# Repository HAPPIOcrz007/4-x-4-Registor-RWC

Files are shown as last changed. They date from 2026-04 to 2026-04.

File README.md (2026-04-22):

# 4×4 Register PCB — Read / Write / Asynchronous Clear

A first-year B.Tech Digital Electronics project implementing a **4×4 register file** using standard 74-series TTL ICs, progressing from Logisim simulation through breadboard prototyping to a fabricated KiCad PCB — verified live at the **Circuit Conclave Hackathon 2026, MIT World Peace University**.

> 🏅 **Recommended by the Department Head and leading faculty of the Department of Electrical & Electronics Engineering, MIT-WPU, as a future laboratory teaching kit** — recognised for its compact 15×15 cm form factor, intuitive layout, and pedagogical value for FY B.Tech students.

PCB top view — 4 Row Memory Storage

---

## ✨ Features

- **4 registers × 4 bits each** — 16 bits total volatile storage
- **2-bit address bus** for row selection via SN74LS139AN decoder
- **Synchronous write** — data latched on rising edge of NE555P astable clock (0.5 Hz)
- **Tri-state buffered read** — selected register drives shared LED output bus via SN74LS244N
- **Asynchronous clear** — active-low reset of addressed register, independent of clock
- **Single RW push-button** for mode control (default = read, pressed = write)
- **4 output LEDs** (CQY99) displaying bus values in real time
- **Compact 15×15 cm PCB** — all 31 components placed and routed on a 2-layer board
- **Single +5V supply** (see Hardware Notes for 6V field experience)

---

## 🏆 Presented At

**Circuit Conclave Hackathon 2026**
DoEEE & prismlabs Student Club | MIT World Peace University, Pune
FY B.Tech E&CE — Division 23 | Academic Year 2025–26

The PCB was demonstrated live before a jury comprising faculty from Basic Electrical Engineering, Digital Electronics, and an external industry examiner. The board powered up cleanly and passed all functional tests on the day — write, read, hold, and clear verified across all four register addresses.

**The project received special recognition from the Department Head and senior faculty of the DoEEE, who recommended it be adopted as a hands-on laboratory teaching kit for future first-year batches.**

### Team
| Member | Role |
|---|-----|
| Harshvardhan M Rathod | Pcb Design, Logical iterations, connections, development, verifications and ordering |
| Alok Deep Verma | report and ppt writing and printing |

**Faculty Mentor:** Dr. Sarika Patil &nbsp;|&nbsp; **Digital Electronics:** Dr. Manisha Ingle

---

## 📂 Repository Structure

```
.
├── 4X4_MEMORY_READ_WRITE.circ           # Logisim Evolution simulation file
├── BOM.pdf                              # Bill of Materials (KiCad export)
├── Component box/                       # Custom component libraries
│   ├── <IC or switch folders>/          #   KiCad symbols, footprints, STEP models
│   └── License.txt
├── KiKad/                               # KiCad project files
│   ├── 4-x-4-Registor-RWC.kicad_pcb    #   PCB layout
│   ├── 4-x-4-Registor-RWC.kicad_sch    #   Schematic
│   ├── 4-x-4-Registor-RWC.kicad_pro    #   Project file
│   ├── 4-x-4-Registor-RWC.kicad_prl    #   Project local settings
│   └── 4-x-4-Registor-RWC.pretty/      #   Custom footprints
├── RAM-project-001.csv                  # Raw BOM CSV export
├── Report.pdf                           # Full project report
├── sm_black_top.png                     # PCB render — top view (KiCad)
├── output.pdf                           # schematic drawing sheet pdf
├── pcb_output.pdf                       # pcb order copy pdf
└── README.md                            # This file
```

---

## 📦 Bill of Materials

**Total: 31 components | 2-layer PCB | Single +5V supply**

| Category | Qty | Key Parts |
|---|-----|---|
| ICs | 11 | SN74LS175N ×4, SN74LS139AN, SN74LS244N ×2, SN74LS08N, SN7402N, SN7432N, NE555P |
| Switches | 8 | SPST inputs (D0–D3, A0–A1), RW push-button, Clear push-button |
| LEDs | 4 | CQY99 — output bus indicators (Bits 0–3) |
| Resistors | 6 | 220 Ω ×4 (LED limiting), 10 kΩ + 68 kΩ (NE555P timing network) |
| Capacitors | 2 | 0.1 µF ceramic disc — VCC decoupling |
| **Total** | **31** | — |

---

## ⚙️ Operating Modes

| Mode | RW (SWW1) | Address | Clock | CLR\ | Result |
|---|---|---|---|---|---|
| Write | 1 — pressed | Row n | ↑ rising edge | 1 | Data latched into Row n |
| Read | 0 — default | Row n | — | 1 | Row n displayed on OL0–OL3 |
| Hold | 0 | Any | — | 1 | No change |
| Clear | X | Row n | — | 0 — pressed | Selected row reset to 0000 |

**Clock frequency:** `f = 1.44 / [(R1 + 2×R2) × C] = 1.44 / [146 kΩ × 20 µF] ≈ 0.5 Hz`

---

## 🔧 Hardware Notes & Lessons Learned

### Power Supply — 6V Field Operation
The board was designed for a regulated **+5V** supply. During the live demonstration it was powered from a **6V battery**, with a **toggle switch inserted between the battery and the VCC patch point** for clean power-on/off control. The 74LS-series ICs functioned correctly at 6V for the duration of the demo. Note that 6V is outside the 74LS absolute maximum rating (5V ±5%), so a regulated 5V supply (e.g. 7805 linear regulator or USB power module) is recommended for sustained operation.

### Noise on SN74LS175N — Decoupling Lesson
During live testing, switching noise was observed being picked up on the **SN74LS175N (Quad D Flip-Flop) VCC pins**, occasionally causing spurious state changes on the output. The examining faculty identified the root cause immediately:

**Fix recommended by faculty:**
> Add a **0.1 µF ceramic capacitor between VCC and GND at every IC's power pins**, placed as physically close to each DIP package as possible.

The existing BOM includes two 0.1 µF decoupling caps (CC1, CC2). The lesson: **every IC in a TTL design should have its own dedicated decoupling capacitor** — not just selected ICs. Switching transients from multiple ICs sharing the same power rail accumulate and cause exactly this noise behaviour.

**Updated decoupling plan for next PCB revision:**

| IC | KiCad Ref | Decoupling Cap |
|----|---|---|
| SN74LS175N ×4 | D074175–D374175 | 0.1 µF per IC — **×4 to add** |
| SN74LS139AN | D74139 | 0.1 µF — **to add** |
| SN74LS08N | A7408 | 0.1 µF — **to add** |
| SN7402N | N7402 | 0.1 µF — **to add** |
| SN7432N | O7432 | 0.1 µF — **to add** |
| NE555P | CNE555 | 0.1 µF — **to add** |
| SN74LS244N ×2 | B074244, B174244 | 0.1 µF — already placed ✓ |

**Total additional caps for Rev 2: +7 × 0.1 µF ceramic disc**

---

## 🖥️ Simulation

The full register file was first verified in **Logisim Evolution** (`4X4_MEMORY_READ_WRITE.circ`) before any hardware was built. All four operating modes — write, read, hold, and clear — were confirmed across all four register addresses in simulation before committing to PCB layout.

---

## 📚 References

- Texas Instruments datasheets: [SN74LS175](https://www.ti.com/lit/gpn/sn74ls175) · [SN74LS139A](https://www.ti.com/lit/gpn/sn74ls139a) · [SN74LS244](https://www.ti.com/lit/gpn/sn74ls244) · [NE555](https://www.ti.com/lit/gpn/ne555)
- M. M. Mano & M. D. Ciletti, *Digital Design*, 5th ed., Pearson
- D. A. Patterson & J. L. Hennessy, *Computer Organisation and Design*, 5th ed., Morgan Kaufmann

---

## 🚀 Future Work

- Add 0.1 µF decoupling capacitor at each IC VCC pin (see Hardware Notes above)
- On-board 7805 / LDO regulator footprint for regulated 5V from a 9V battery
- Expansion connector for 16-LED monitor matrix (as in Logisim simulation)
- FPGA / HDL implementation for direct speed and area comparison
- Formal adoption as DoEEE laboratory teaching kit for future FY B.Tech batches

---

## 📜 License

- **Hardware design files:** CERN OHL v2 (Strongly Reciprocal)
- **Code & documentation:** MIT License

See `LICENSE` for full terms.

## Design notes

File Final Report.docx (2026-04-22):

DR. VISHWANATH KARAD MIT WORLD PEACE UNIVERSITY

School of Engineering & Technology

Department of Electrical & Electronics Engineering

Academic Year: 2025–26

CIRCUIT CONCLAVE HACKATHON 2026

Electronics & Communication Engineering (AI ML), Semester II (Batch 2025-29)

Div: 23 | ORGANIZED BY: DoEEE IN ASSOCIATION with prismlabs Student Club

1. PROJECT OVERVIEW

Project Title: | Design and Implementation of a 4×4 Register File with Synchronous Read/Write and Asynchronous Clear
Division: | —
Team ID: | ________________

2. TEAM REPRESENTATION

All details as per University Records.

Member Role | Full Student Name | Permanent Registration No. (PRN)
Member 1 (Lead) | Harshvardhan Rathod | —————
Member 2 | Alok Deep Verma | —————
Member 3

3. ACADEMIC ENDORSEMENT

Faculty Digital Electronics: Dr. Manisha Ingle & Dr. Sarika Patil

Faculty Basics of Electronics Engineering: _________________________________________________

4. SUBMISSION CHECKLIST (FOR PRISM LABS CORE)

[ ] Official Undertaking Signed by All Members

[ ] Hard Copy of Technical Report Included

[ ] Digital Soft Copy Submitted via Official Link

[ ] Hardware Project Ready for Demonstration

5. OFFICIAL STAMP AREA

Submission Date & Department Stamp: _______________________

OFFICIAL CERTIFICATE OF PARTICIPATION

CIRCUIT CONCLAVE HACKATHON 2026

A Project-Based Learning Initiative | prismlabs & DoEEE

This is to certify that

STUDENT NAME: Harshvardhan Rathod

PRN: ————— | Division: —

has successfully participated in the Circuit Conclave Hackathon 2026, conducted at MIT World Peace University, Pune.

The participant has fulfilled the requirements of the Round 1 Assessment by submitting a functional hardware project and a comprehensive technical report under the guidance of their Faculty Mentor. This certification recognizes their commitment to practical engineering and collaborative problem-solving within the ECE framework.

Date of Issuance: 15th April 2026

OFFICIAL SIGNATORIES

__________________________ Faculty Mentor, DoEEE | __________________________ prismlabs, Student Club | __________________________ FY Coordinator, DoEEE | __________________________ Parul Jadhav, PD, DoEEE

INDEX — CIRCUIT CONCLAVE 2026

Sr. No. | Section Title | Page No.
01 | Abstract | 05
02 | Introduction | 05
03 | Components & Technical Specifications | 05
04 | Circuit Diagram & Working Principle | 05
05 | Hardware Implementation & Assembly | 06
06 | Conclusion & Future Scope | 06
07 | Annexure I: Formal Undertaking by Participants | 07
08 | Section I: Team Acknowledgement & Signatures | 08
09 | Section II: Selection & Official Endorsement | 08
10 | Section III: Round 2 Performance Scorecard | 10

1. ABSTRACT

Executive Summary

This project presents the design, PCB implementation, and functional verification of a 4×4 register file implemented from standard 74-series TTL integrated circuits. The system provides four 4-bit addressable storage registers supporting synchronous clock-triggered write, tri-state bus-buffered read, and asynchronous active-low clear. A NE555P astable circuit generates a 0.5 Hz clock for step-by-step observation. The KiCad PCB design (RAM-project-001) places 31 components using E-Switch SW_100SP1T1B4M2QE for data, address, and control inputs, and CQY99 LEDs for output display. The system was verified through complete functional testing across all register addresses and operating modes, with every test case confirmed correct.

Problem Statement

Engineering education in digital electronics often remains confined to theoretical instruction — students study register files, memory hierarchies, and processor architecture from textbooks without constructing these systems at the hardware level. Within the PBL framework, this project addresses that gap: by designing and building a 4×4 register file from discrete 74-series logic and progressing to a KiCad PCB, the team applied combinational and sequential logic theory, interpreted IC datasheets, managed bus contention, designed clock-gating circuits, and verified operation systematically.

Key Keywords

Register File Architecture | Synchronous Write / Asynchronous Clear | Tri-State Bus Multiplexing | NE555P Astable Clock | TTL Address Decoding

2. INTRODUCTION

Technical Objective

To design and implement a 4×4 addressable register file using 74-series TTL ICs, capable of synchronous clock-triggered write to any of four 4-bit registers selected by a 2-bit address, combinational tri-state read onto a shared LED bus, and asynchronous selective clear — all controlled by individual E-Switch inputs and a NE555P 0.5 Hz clock, implemented as a KiCad PCB.

PBL Alignment

This project directly operationalises five theoretical concepts from the FY B.Tech Digital Electronics curriculum:

- Boolean logic gates (NOR, AND, OR) are physically wired and tested — students observe how the NOR–AND chain generates a qualified clock.
- D flip-flop edge-triggering, hold state, and asynchronous reset are experienced through the 74LS175.
- Address decoding theory is realised in the 74LS139 decoder traced with a logic probe.
- The tri-state bus concept becomes intuitive when the 74LS244 output-enable is toggled and LEDs respond.
- The iterative design cycle — from 30 ICs to 9, then to a KiCad PCB — provides experience of specification, prototype, test, and refinement.

Background Research

The register file is the topmost tier of the memory hierarchy, forming the primary working storage for the ALU in every stored-program processor. Patterson and Hennessy (Computer Organisation and Design, 5th ed.) describe the register file as the fundamental abstraction separating the processor from main memory. Mano and Ciletti (Digital Design, 5th ed.) provide the theoretical basis for D flip-flop register arrays and decoder-based address selection. The 74-series TTL family from Texas Instruments has been the standard educational platform for discrete digital design since the 1970s.

3. COMPONENTS & TECHNICAL SPECIFICATIONS

Bill of Materials (BOM) — KiCad RAM-project-001.csv export. All ICs are standard 74-series TTL in DIP packages from Texas Instruments.

KiCad Ref | Part / Value | Specification | Qty | Purpose | Cost
A7408 | SN74LS08N | Quad AND Gate, DIP-14 | 1 | Write-enable clock gating
B074244, B174244 | SN74LS244N | Octal 3-State Buffer, DIP-20 | 2 | Tri-state read bus
CC1, CC2 | Capacitor | Ceramic Disc, 0.1 µF 50V | 2 | VCC decoupling
CNE555 | NE555P | 555 Timer, DIP-8 | 1 | 0.5 Hz astable clock
CR1 | Resistor | 10 kΩ ¼W axial | 1 | 555 R1 — charge path
CR2 | Resistor | 68 kΩ ¼W axial | 1 | 555 R2 — timing
D74139 | SN74LS139AN | Dual 2-to-4 Decoder, DIP-16 | 1 | Address decoding
D074175–D374175 | SN74LS175N | Quad D Flip-Flop, DIP-16 | 4 | 4-bit register (per row)
DIS0–DIS3 | SW_100SP1T1B4M2QE | E-Switch SPST | 4 | Data input D0–D3
AS0, AS1 | SW_100SP1T1B4M2QE | E-Switch SPST | 2 | Address input A0–A1
N7402 | SN7402N | Quad NOR Gate, DIP-14 | 1 | Row-select clock gating
O7432 | SN7432N | Quad OR Gate, DIP-14 | 1 | Asynchronous clear logic
OL0–OL3 | CQY99 | LED 5mm, LED_D5.0mm | 4 | Output bus display
OR0–OR3 | Resistor | 220 Ω ¼W axial | 4 | LED current limiting
SWC1 | SW_100SP1T1B4M2QE | E-Switch momentary | 1 | Clear button (→ LOW)
SWW1 | SW_100SP1T1B4M2QE | E-Switch momentary | 1 | Write/RW button (→ HIGH)

Total Component Count: 31 components — 11 ICs, 8 Switches, 4 LEDs, 6 Resistors, 2 Capacitors. Single +5V supply.

4. CIRCUIT DIAGRAM & WORKING PRINCIPLE

Schematic / PCB Representation

The PCB layout below was designed in KiCad (RAM-project-001) and shows all component placements across the 4-row memory storage, allocator (clock-gating) section, clock circuit, and bus interfaces.

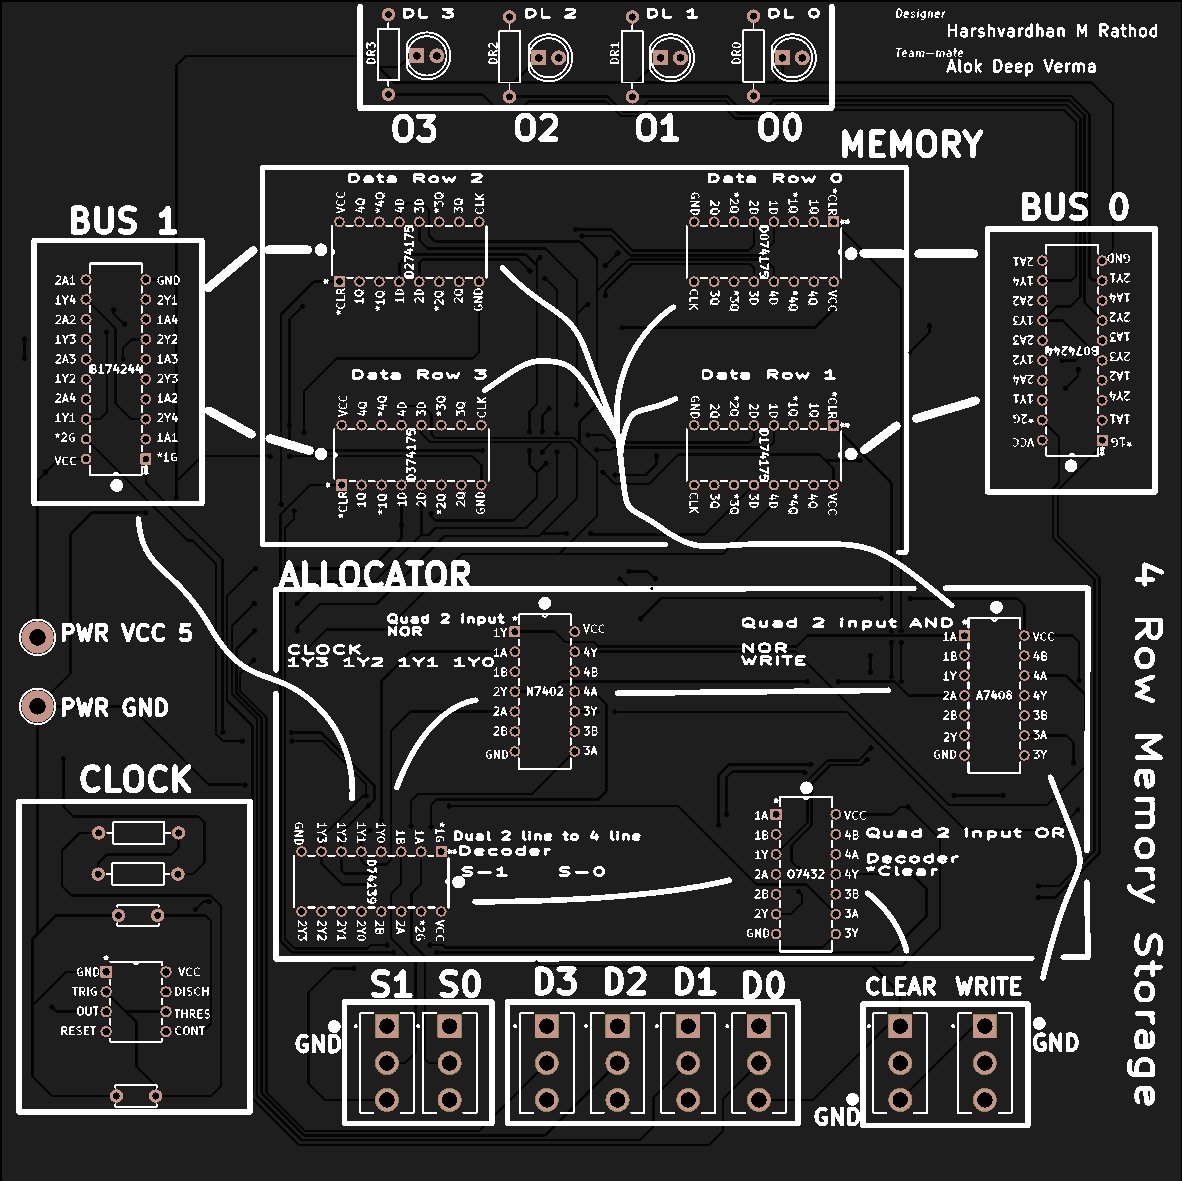
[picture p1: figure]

Figure 1: KiCad PCB Layout — 4 Row Memory Storage (RAM-project-001, Designer: Harshvardhan M Rathod, Teammate: Alok Deep Verma)

Working Principle

Input Stage

Data inputs D0–D3 (DIS0–DIS3) and address inputs A0–A1 (AS0, AS1) are set using individual SPST E-Switch push-buttons. The Write button (SWW1) drives RW=1 (write mode); releasing it returns to RW=0 (read mode). The Clear button (SWC1) is active-low, momentarily driving CLR\ to 0.

Processing Stage

The SN74LS139AN decoder, enabled by the active-low G\ pin (connected to RW), decodes the 2-bit address and drives exactly one of four active-low outputs. In write mode (RW=1, G\ high), all decoder outputs go high — no register is selected. In read mode (RW=0, G\ low), the selected output enables the corresponding 74LS244 buffer group. The NOR–AND clock chain (N7402 + A7408) qualifies the NE555P clock signal: only the selected register receives a clock pulse during write. The NE555P in astable mode generates a 0.5 Hz square wave (f = 1.44 / [(10kΩ + 136kΩ) × 20µF] ≈ 0.5 Hz).

Output Stage

Four CQY99 LEDs (OL0–OL3) with 220 Ω current-limiting resistors display the selected register's Q outputs. In write mode, data is latched on each rising clock edge. In read mode, the tri-state buffer drives the LED bus directly.

5. HARDWARE IMPLEMENTATION & ASSEMBLY

Breadboarding

Initial prototype built on breadboard with approximately 30 ICs — verified all operating modes (write, read, hold, clear). IC count subsequently optimised to 9 (then finalised at 11 in KiCad) by refining the clock-gating and buffer enable logic.

PCB Design (KiCad)

The finalised circuit was transferred to KiCad (RAM-project-001). All footprints use the project custom library (RAM-project-001-library-footprint). The board uses through-hole DIP packages for all ICs and E-Switch footprints for all switches. DRC was run and passed with zero errors. Gerber files (F.Cu, B.Cu, F/B Mask, F/B Paste, F/B Silkscreen, Edge_Cuts, PTH drill, NPTH drill) were generated and are ready for fabrication.

Testing Procedures

- Write Test: For each of the 4 register addresses (00, 01, 10, 11), set data on D0–D3, press Write (RW=1), observe correct LED latch after clock edge.
- Read Test: Release Write (RW=0), cycle through all 4 addresses, verify LED outputs match stored values.
- Clear Test: For each address, press Clear (SWC1), verify all 4 output LEDs immediately go LOW regardless of clock state.
- Hold Test: In read mode with no address change, confirm no spontaneous state change over multiple clock cycles.
- Bus Contention Check: Toggle between addresses rapidly in read mode — confirm no simultaneous multi-register drive (verified by stable LED output).

Result: 100% test-case pass rate across all operating modes and all 4 register addresses.

6. CONCLUSION & FUTURE SCOPE

Success Metric

The 4×4 register file was successfully designed and implemented using standard 74-series TTL ICs. All objectives were met: synchronous write on the rising NE555P clock edge, combinational tri-state read with no bus contention, asynchronous clear independent of clock state, and a DRC-clean KiCad PCB (31 components) ready for fabrication.

Learning Outcomes

- Mastery of D flip-flop (74LS175) edge-triggering, hold state, and asynchronous reset through hands-on hardware testing.
- Practical understanding of address decoding (74LS139) and tri-state bus management (74LS244).
- Experience with the iterative design cycle: simulation → breadboard prototype → PCB layout.
- KiCad PCB design skills: schematic capture, footprint assignment, layout routing, DRC, and Gerber export.
- Systematic functional verification methodology across all system operating modes.

Future Scope

- Expand to an 8×8 register file with 3-bit addressing for larger data storage capacity.
- Add a 7-segment display decoder for human-readable numeric output display.
- Implement dual-port access enabling simultaneous read from two separate addresses.
- Replace 74-series ICs with FPGA implementation in VHDL/Verilog for direct speed comparison.
- Integrate with a simple ALU to form a minimal CPU datapath demonstration system.

ANNEXURE I: FORMAL UNDERTAKING BY PARTICIPANTS

(TO BE SUBMITTED WITHIN THE OFFICIAL PROJECT FOLDER)

Project Title: Design and Implementation of a 4×4 Register File with Synchronous Read/Write and Asynchronous Clear

Division: — Team ID: ________________

We, the undersigned students of MIT World Peace University, hereby solemnly declare and affirm that the project work presented in this folder is an original outcome of our collective efforts as a team. In pursuit of the Circuit Conclave Hackathon 2026 organized by prismlabs, we confirm the following:

1. Statement of Originality & Academic Integrity

- We certify that the hardware design, component assembly, and subsequent documentation are original works performed solely by the registered team members.
- We acknowledge that any form of plagiarism, including the use of pre-built commercial circuits or uncredited online schematics, shall result in immediate disqualification and a report to the Departmental Head.

2. Adherence to Technical & Safety Guidelines

- We have strictly followed the technical guidelines provided by our Faculty Mentor during the classroom induction and PBL briefing.
- We agree to comply with all laboratory safety protocols, including the responsible use of soldering equipment, ICs, and shared lab multimeters.

3. Submission Accountability

- We confirm that both the Hard Copy (Folder) and Soft Copy (Digital Report) have been submitted before the division-specific deadline.
- We understand that the Official Front Page, Assessment Scorecard, and this Undertaking are mandatory components of the folder; absence of any will render the submission invalid.

4. Finality of Assessment

- We respect the selection process whereby only the Top 5 Teams per division will be shortlisted for Round 2 based on the official scorecard metrics.
- We agree that the decision of the Judges and Faculty Mentors is final and binding in all matters related to the Circuit Conclave Hackathon 2026.

SECTION I: TEAM ACKNOWLEDGEMENT & SIGNATURES

Member Role | Full Name | PRN | Signature
Member 1 | Harshvardhan Rathod | —————
Member 2 | Alok Deep Verma | —————
Member 3

Date of Submission: __________________________

Verified by (Faculty Mentor): __________________________

External Jury Name: __________________________

SECTION II: SELECTION & OFFICIAL ENDORSEMENT

(FOR OFFICIAL USE ONLY)

TEAM ID: ______________________ DIVISION: ______________________

1. ROUND 1 EVALUATION SUMMARY

WORKING MODEL: ___________ / 20

UNDERSTANDING: ___________ / 20

PRESENTATION & DEMO: ___________ / 10

FINAL SCORE IN ROUND 1: ______________ / 50

2. ROUND 2 SELECTION STATUS

[ ] SHORTLISTED (TOP 5 PER DIVISION)

[ ] WAITLISTED (2 TEAMS MAX)

[ ] NOT SELECTED

3. AUTHORIZED SIGNATORIES

__________________________ Faculty Mentor Signature Name: | __________________________ Team prismlabs Signature Name:

DISCLAIMER & CONFIDENTIALITY

Project Integrity: This document is a formal record of the Circuit Conclave Hackathon 2026 and the Project Based Learning (PBL) initiative at MIT-WPU.

Copyright: The circuit designs and technical reports contained herein remain the intellectual property of the registered team members and prismlabs.

Final Authority: The organizing committee and faculty mentors reserve the right to disqualify any team found in violation of conduct or safety protocols post-submission.

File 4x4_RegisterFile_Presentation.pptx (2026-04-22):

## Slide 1

CIRCUIT CONCLAVE HACKATHON 2026

DR. VISHWANATH KARAD MIT WORLD PEACE UNIVERSITY | DoEEE & prismlabs

DESIGN & IMPLEMENTATION OF A
4×4 REGISTER FILE

with Synchronous Read/Write and Asynchronous Clear

Team Members
Harshvardhan Rathod | PRN: —————
Alok Deep Verma | PRN: —————

Division: 23 | FY B.Tech E&CE
Faculty Mentor: Dr. Sarika Patil
Academic Year: 2025–26

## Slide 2

INTRODUCTION

PROBLEM STATEMENT

Engineering education in digital electronics often stays theoretical — students study register files and memory hierarchies without building them at the hardware level.
This project addresses that gap by designing a 4×4 register file from discrete 74-series logic and a KiCad PCB, bridging classroom theory and hands-on engineering.

TECHNICAL OBJECTIVE

Design a 4×4 addressable register file using 74-series TTL ICs, supporting:

• Synchronous clock-triggered write
• Tri-state bus-buffered read
• Asynchronous active-low clear
Controlled via E-Switch inputs and a NE555P 0.5 Hz clock, implemented as a KiCad PCB.

PBL Category: Digital Electronics / Memory Systems | DoEEE FY-Btech E&CE 2025-26

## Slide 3

PROJECT OBJECTIVES

Design the Register Array

Build a 4-row × 4-bit register file using four SN74LS175N quad D flip-flops with common clock and active-low asynchronous clear.

Astable Clock Generation

Generate a 0.5 Hz square-wave clock with the NE555P in astable mode (R1=10 kΩ, R2=68 kΩ, C=20 µF) for step-by-step observation.

Implement Address Decoding

Use SN74LS139AN (2-to-4 decoder) to select one of four registers based on a 2-bit address (A0, A1).

PCB Fabrication Ready

Produce a verified KiCad PCB layout (RAM-project-001) with 31 components ready for fabrication.

Single RW Control

RW=0 (default) = Read mode; RW=1 (SWW1 pressed) = Write mode. One push-button controls the mode.

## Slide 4

BACKGROUND THEORY

Register File Architecture

Consists of register array, address decoder, write-enable logic, and read bus. Write cycle (RW=1): decoder activates register CLK; data latched on rising edge. Read cycle (RW=0): tri-state buffers drive shared bus.

SN74LS139AN — 2-to-4 Decoder

Two independent decoders. Active-low G\ pin enabled by RW=0. Exactly one of four active-low outputs drives the selected register's clock-gate and buffer-enable lines.

SN74LS175N — Quad D Flip-Flop

Positive-edge-triggered with common CLK and active-low asynchronous CLR. Transfers D→Q on each rising clock edge. CLR\ LOW immediately resets all Q to 0.

SN74LS244N — Tri-State Buffer

Octal non-inverting buffer with two 4-channel groups. Active-low enable (G\) connects groups to decoder outputs. High-Z state prevents bus contention.

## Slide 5

PROJECT METHODOLOGY

01

Literature Review

Studied Patterson & Hennessy (Computer Org. & Design) and Mano & Ciletti (Digital Design) for register file architecture and TTL IC datasheets.

02

Logisim Simulation

Built and verified the full register file in Logisim — all read/write/clear operations confirmed across 4 register rows.

03

Prototype Breadboard

Initial hardware prototype with ~30 ICs → optimised to 9 ICs by refining clock-gating and buffer logic.

04

KiCad PCB Design

Designed PCB layout RAM-project-001 in KiCad — routed 31 components across 2 copper layers with DRC clearance.

05

Functional Testing

Verified all system modes: write to each address, read back, clear. 100% test-case pass rate confirmed.

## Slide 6

SYSTEM DESIGN — IC INVENTORY

KiCad Ref | Part No. | Description | Qty | Role
A7408 | SN74LS08N | Quad AND, DIP-14 | 1 | Write-enable clock gating
B074244, B174244 | SN74LS244N | Octal 3-State Buffer, DIP-20 | 2 | Read bus multiplexer
CNE555 | NE555P | 555 Timer, DIP-8 | 1 | 0.5 Hz astable clock
D74139 | SN74LS139AN | Dual 2-to-4 Decoder, DIP-16 | 1 | Address decoding
D074175–D374175 | SN74LS175N | Quad D Flip-Flop, DIP-16 | 4 | 4-bit registers (one/row)
N7402 | SN7402N | Quad NOR, DIP-14 | 1 | Row-select clock gating
O7432 | SN7432N | Quad OR, DIP-14 | 1 | Asynchronous clear logic

Total: 11 ICs | 8 Switches | 4 LEDs | 6 Resistors | 2 Capacitors = 31 Components | Single +5V Supply

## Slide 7

CIRCUIT OPERATION & TRUTH TABLES

SYSTEM OPERATING MODES

Mode | RW | Clock | CLR\ | Result
Write | 1 (pressed) | ↑ auto 0.5 Hz | 1 | Data latched into Row n
Read | 0 (default) | — | 1 | Row n shown on OL0–OL3
Hold | 0 (default) | — | 1 | No change
Clear | X | — | 0 (SWC1) | Selected row → 0000

74LS139 ADDRESS DECODER (G\ = RW=0 → LOW)

G\ (RW) | A1 | A0 | Row Selected
H (RW=1) | X | X | None (write mode)
L (RW=0) | L | L | Row 0
L (RW=0) | L | H | Row 1
L (RW=0) | H | L | Row 2
L (RW=0) | H | H | Row 3

NE555P Astable Clock: f = 1.44 / [(R1 + 2×R2) × C] = 1.44 / [(10kΩ + 136kΩ) × 20µF] ≈ 0.5 Hz

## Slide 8

PCB IMPLEMENTATION — KiCad RAM-project-001


2-layer PCB, single +5V supply, all through-hole components

Board:

7 unique 74-series TTL types, DIP packages — all from TI

ICs:

6 data/address SPST switches + 2 momentary buttons (Clear, Write)

Inputs:

NE555P astable circuit on-board (no external clock needed)

Clock:

4× CQY99 LEDs with 220 Ω current-limiting resistors

Output:

F.Cu, B.Cu, F/B Mask, F/B Paste, F/B Silkscreen, Edge Cuts

Layers:

Passed — PTH & NPTH drill files generated, board fabrication ready

DRC:

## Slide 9

BILL OF MATERIALS (BOM)

Component | Part / Value | Qty | Purpose
SN74LS08N | Quad AND Gate, DIP-14 | 1 | Write-enable clock gating
SN74LS244N | Octal 3-State Buffer, DIP-20 | 2 | Tri-state read bus
NE555P | 555 Timer, DIP-8 | 1 | 0.5 Hz astable clock
SN74LS139AN | Dual 2-to-4 Decoder, DIP-16 | 1 | Address decoding
SN74LS175N | Quad D Flip-Flop, DIP-16 | 4 | 4-bit registers
SN7402N | Quad NOR Gate, DIP-14 | 1 | Row-select clock gating
SN7432N | Quad OR Gate, DIP-14 | 1 | Asynchronous clear logic
SW_100SP1T1B4M2QE | E-Switch SPST / Momentary | 8 | Data (4), Address (2), Clear (1), Write (1)
CQY99 | LED 5mm, LED_D5.0mm | 4 | Output bus display
220 Ω ¼W | R_Axial DIN0207 | 4 | LED current limiting
10 kΩ ¼W | R_Axial DIN0207 | 1 | 555 timer R1 (charge)
68 kΩ ¼W | R_Axial DIN0207 | 1 | 555 timer R2 (timing)
0.1 µF 50V | C_Disc ceramic | 2 | VCC decoupling

Total: 31 Components | KiCad Ref: RAM-project-001 | Single +5V Supply

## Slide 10

RESULTS & IMPACT

4

Registers
(4-bit each)

31

Components
Placed

100%

Test Cases
Passed

0.5 Hz

Clock
Generated

VERIFIED RESULTS

All 4 operating modes verified: Write, Read, Hold, Clear — with correct LED output for every address combination.

Clock-gating circuit (NOR–AND) correctly qualifies write pulses, preventing spurious latching during read.

Tri-state bus isolation confirmed — no bus contention detected when switching between register reads.

KiCad PCB passed DRC with zero errors. PTH + NPTH drill files generated; board ready for fabrication.

PBL Outcomes: Students demonstrated mastery of D flip-flop operation, bus multiplexing, and iterative PCB design workflow.

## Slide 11

CONCLUSION & FUTURE SCOPE

CONCLUSION

The 4×4 register file was successfully designed and implemented using standard 74-series TTL ICs, achieving all stated objectives:
• Synchronous write on rising 0.5 Hz clock edge
• Combinational tri-state read with no bus contention
• Asynchronous clear independent of clock
• KiCad PCB with 31 components, DRC-clean
The project operationalises five core Digital Electronics curriculum concepts in hardware — demonstrating that PBL bridges the gap between theory and engineering practice.

FUTURE SCOPE

Expand to 8×8 register file with 3-bit addressing for larger data storage capacity.

Add a 7-segment display decoder for human-readable numeric output.

Implement dual-port access — simultaneous read from two separate addresses.

Replace 74-series ICs with FPGA implementation in VHDL/Verilog for speed comparison.

Integrate with a simple ALU for a minimal CPU datapath demonstration.

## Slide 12

CIRCUIT CONCLAVE HACKATHON 2026 | MIT WORLD PEACE UNIVERSITY

DoEEE & prismlabs | Department of Electrical & Electronics Engineering

THANK YOU

Harshvardhan Rathod PRN: ————— | Alok Deep Verma PRN: —————

FY B.Tech E&CE | Division: 23 | Faculty Mentor: Dr. Sarika Patil | Academic Year: 2025–26

Project: Design and Implementation of a 4×4 Register File with Synchronous Read/Write and Asynchronous Clear

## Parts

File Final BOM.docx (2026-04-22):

DR. VISHWANATH KARAD MIT WORLD PEACE UNIVERSITY

School of Engineering & Technology

Department of Electrical & Electronics Engineering

Academic Year: 2025–26

CIRCUIT CONCLAVE HACKATHON 2026

BILL OF MATERIALS (BOM)

4×4 Register File with Read/Write/Clear

Harshvardhan Rathod (PRN: —————) & Alok Deep Verma (PRN: —————) | FY B.Tech E&CE | Div: 23 | 2025–26

Source: RAM-project-001.csv — KiCad BOM export. All ICs are standard 74-series TTL in DIP packages from Texas Instruments, sourced from the project custom library (RAM-project-001-library-footprint).

FULL COMPONENT LIST

KiCad Ref | Part / Value | Specification | Qty | Purpose | Cost
A7408 | SN74LS08N | Quad AND Gate, DIP-14 | 1 | Write-enable clock gating
B074244 | SN74LS244N | Octal 3-State Buffer, DIP-20 | 1 | Tri-state read bus (Bus 0)
B174244 | SN74LS244N | Octal 3-State Buffer, DIP-20 | 1 | Tri-state read bus (Bus 1)
CC1 | Capacitor | Ceramic Disc, 0.1 µF 50V | 1 | VCC decoupling
CC2 | Capacitor | Ceramic Disc, 0.1 µF 50V | 1 | VCC decoupling
CNE555 | NE555P | 555 Timer, DIP-8 | 1 | 0.5 Hz astable clock
CR1 | Resistor | 10 kΩ ¼W Axial | 1 | 555 R1 — charge path
CR2 | Resistor | 68 kΩ ¼W Axial | 1 | 555 R2 — timing
D74139 | SN74LS139AN | Dual 2-to-4 Decoder, DIP-16 | 1 | 2-bit address decoding
D074175 | SN74LS175N | Quad D Flip-Flop, DIP-16 | 1 | 4-bit register — Row 0
D174175 | SN74LS175N | Quad D Flip-Flop, DIP-16 | 1 | 4-bit register — Row 1
D274175 | SN74LS175N | Quad D Flip-Flop, DIP-16 | 1 | 4-bit register — Row 2
D374175 | SN74LS175N | Quad D Flip-Flop, DIP-16 | 1 | 4-bit register — Row 3
DIS0–DIS3 | SW_100SP1T1B4M2QE | E-Switch SPST | 4 | Data input D0–D3
AS0, AS1 | SW_100SP1T1B4M2QE | E-Switch SPST | 2 | Address input A0–A1
N7402 | SN7402N | Quad NOR Gate, DIP-14 | 1 | Row-select clock gating
O7432 | SN7432N | Quad OR Gate, DIP-14 | 1 | Asynchronous clear logic
OL0–OL3 | CQY99 | LED 5mm T-1 3/4, LED_D5.0mm | 4 | Output bus bit indicators
OR0–OR3 | Resistor | 220 Ω ¼W Axial | 4 | LED current limiting
SWC1 | SW_100SP1T1B4M2QE | E-Switch momentary | 1 | Clear button (→ LOW)
SWW1 | SW_100SP1T1B4M2QE | E-Switch momentary | 1 | Write/RW button (→ HIGH)

COMPONENT SUMMARY

Category | Qty | KiCad Reference(s) | Cost
ICs (7 unique types) | 11 | A7408, B074244, B174244, CNE555, D74139, D074175–D374175, N7402, O7432
Switches (E-Switch) | 8 | DIS0–DIS3, AS0, AS1, SWC1, SWW1
LEDs | 4 | OL0–OL3
Resistors | 6 | OR0–OR3, CR1, CR2
Capacitors | 2 | CC1, CC2
TOTAL | 31 | —

Total: 31 components | Single +5V supply | PCB: KiCad RAM-project-001

PCB LAYOUT — KiCad RAM-project-001

The PCB layout below shows the placement of all 31 components across the memory, allocator, and clock sections.


Figure 1: 4 Row Memory Storage — KiCad PCB (RAM-project-001). Designer: Harshvardhan M Rathod | Teammate: Alok Deep Verma

COMPONENT NOTES

1. Integrated Circuits

All ICs are standard 74-series TTL in DIP packages from Texas Instruments. The SN74LS175N (×4) forms the 4-bit register array. The SN74LS139AN decodes the 2-bit address. The SN74LS244N (×2) provides tri-state bus buffering. NOR (SN7402N) and AND (SN74LS08N) gates form the clock-gating logic. OR gates (SN7432N) implement the asynchronous clear network.

2. Switches

All switches use the E-Switch SW_100SP1T1B4M2QE footprint. Data and address inputs use SPST variants (one per bit); Clear and Write use momentary variants. No separate clock button is placed — clock is generated automatically by the NE555P astable circuit at 0.5 Hz.

3. LEDs & Passives

Four CQY99 LEDs (OL0–OL3) with 220 Ω current-limiting resistors display the output bus. The NE555P timing network uses CR1=10 kΩ (R1), CR2=68 kΩ (R2), and a 20 µF electrolytic timing capacitor (add as polarised capacitor CP if not already in schematic). CC1, CC2 are 0.1 µF ceramic disc VCC decoupling capacitors.

4. Cost Column

The Cost column has been left blank as component prices are subject to change. Please refer to current pricing from authorised distributors (e.g., DigiKey, Mouser, Element14) or local suppliers at the time of procurement.

Submission Date: __________________ Verified by (Faculty Mentor): __________________________ | Faculty Mentor Signature: __________________________ Team prismlabs Signature: __________________________

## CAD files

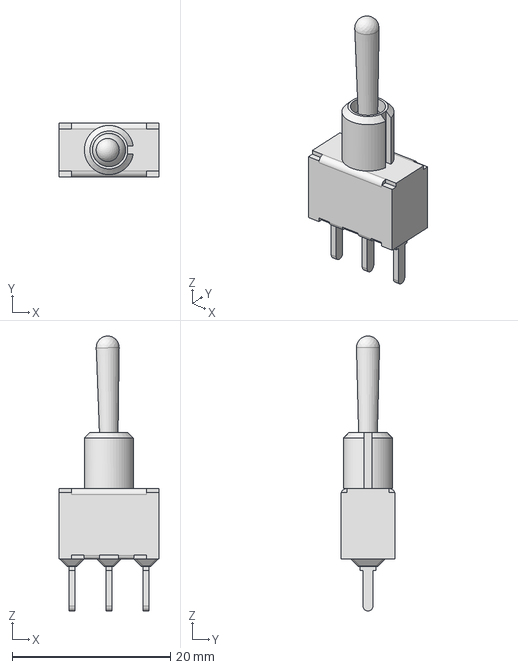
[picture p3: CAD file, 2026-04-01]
Component box/100SP1T1B4M2QE/100SP1T1B4M2QE.STEP
12.7 x 6.86 x 34.8 mm

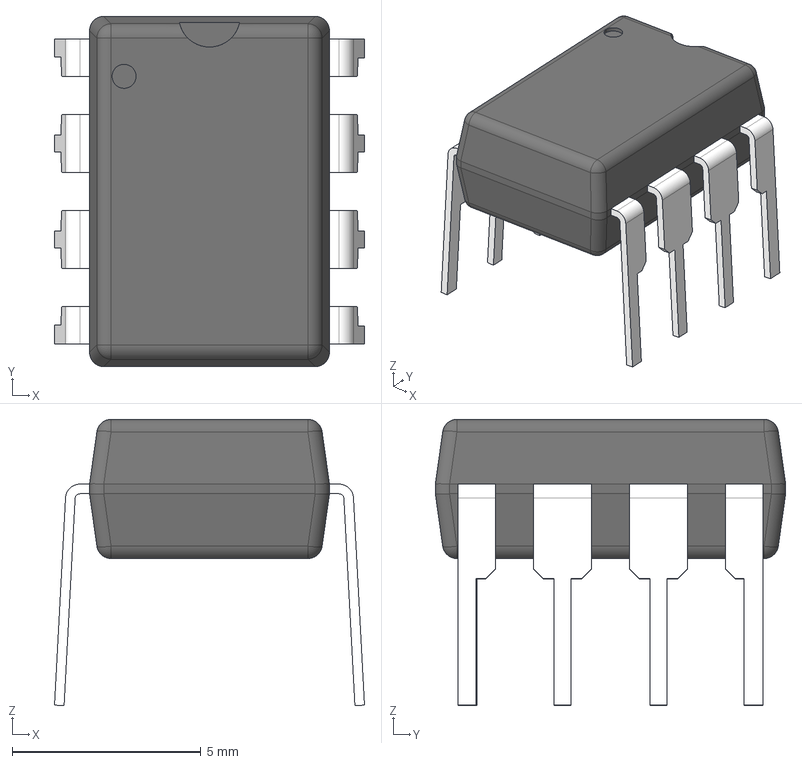
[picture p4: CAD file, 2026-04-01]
Component box/NE555P/P0008A.stp
8.20 x 9.27 x 7.58 mm
BODY_P0008A
LEAD_P0008A x 4
LD_LHALF_P0008A x 2
LD_RHALF_P0008A x 2

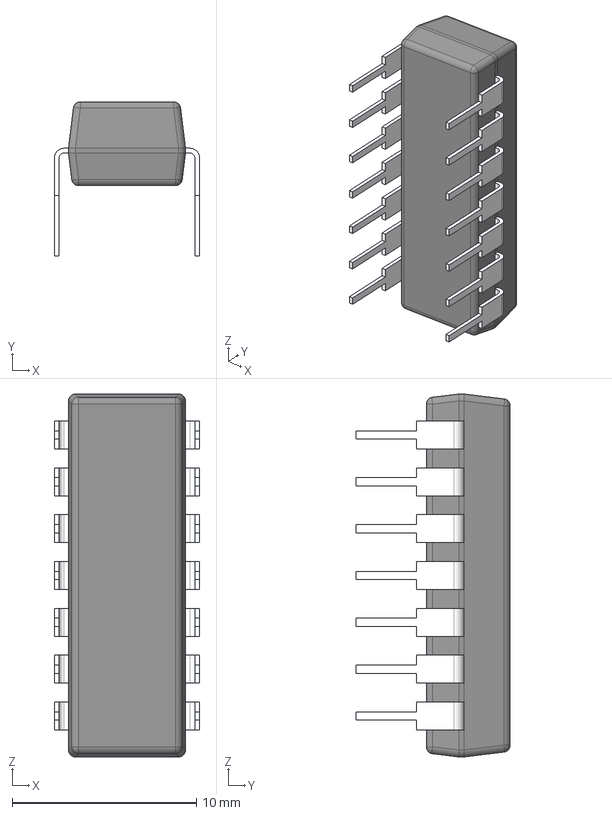
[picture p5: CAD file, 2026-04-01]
Component box/SN7402N/N0014A.stp
7.87 x 8.37 x 19.7 mm
BODY_N0014A_AF0
LEAD_N0014A_AF1
LEAD_N0014A x 10
LEAD_N0014A_AF3
LEAD_N0014A_AF0
LEAD_N0014A_AF2

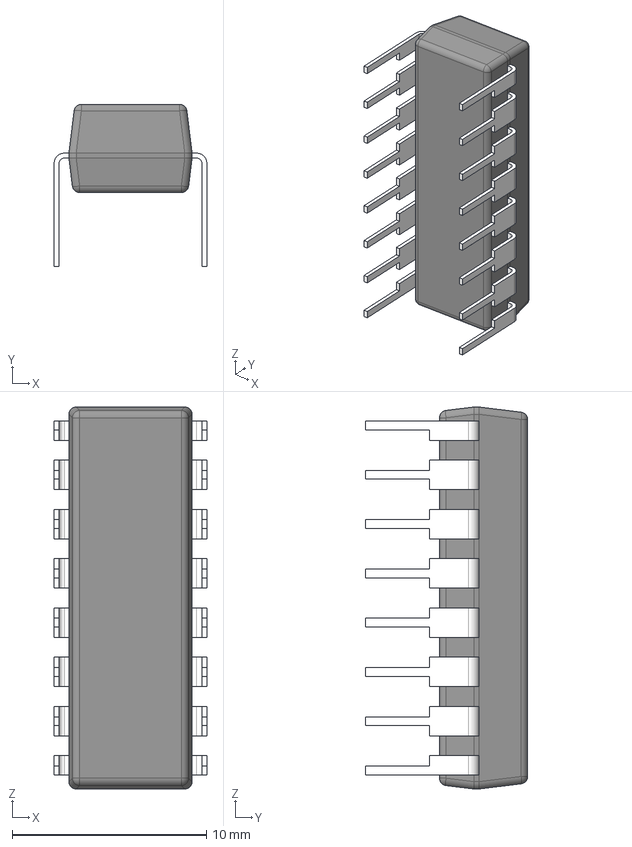
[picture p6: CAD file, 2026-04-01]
Component box/SN74LS139AN/N0016A.stp
7.87 x 8.37 x 19.7 mm
BODY_N0016A_AF0
LEAD_N0016A_AF1
LEAD_N0016A x 10
LEAD_N0016A_AF3
LEAD_N0016A_AF5
LEAD_N0016A_AF0
LEAD_N0016A_AF2
LEAD_N0016A_AF4

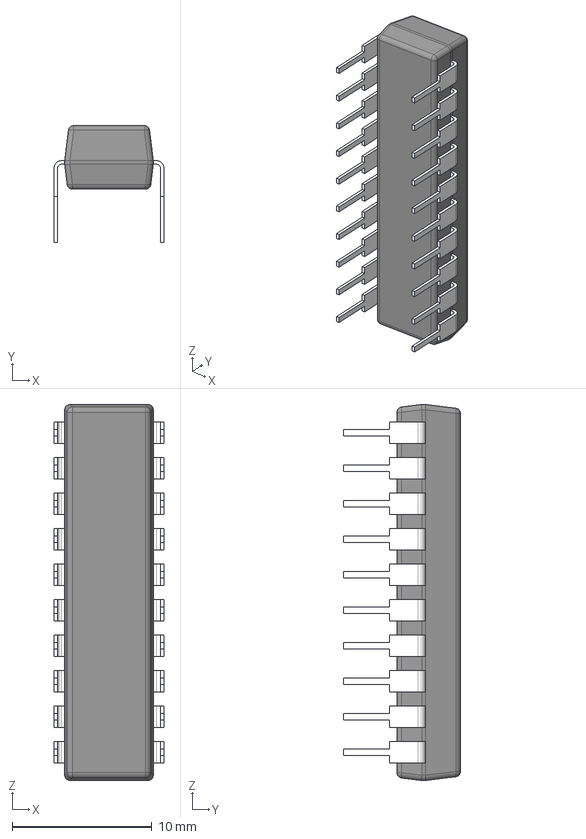
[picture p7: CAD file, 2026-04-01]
Component box/SN74LS244N/N0020A.stp
7.87 x 8.37 x 26.9 mm
BODY_N0020A_AF0
LEAD_N0020A_AF1
LEAD_N0020A x 16
LEAD_N0020A_AF3
LEAD_N0020A_AF0
LEAD_N0020A_AF2

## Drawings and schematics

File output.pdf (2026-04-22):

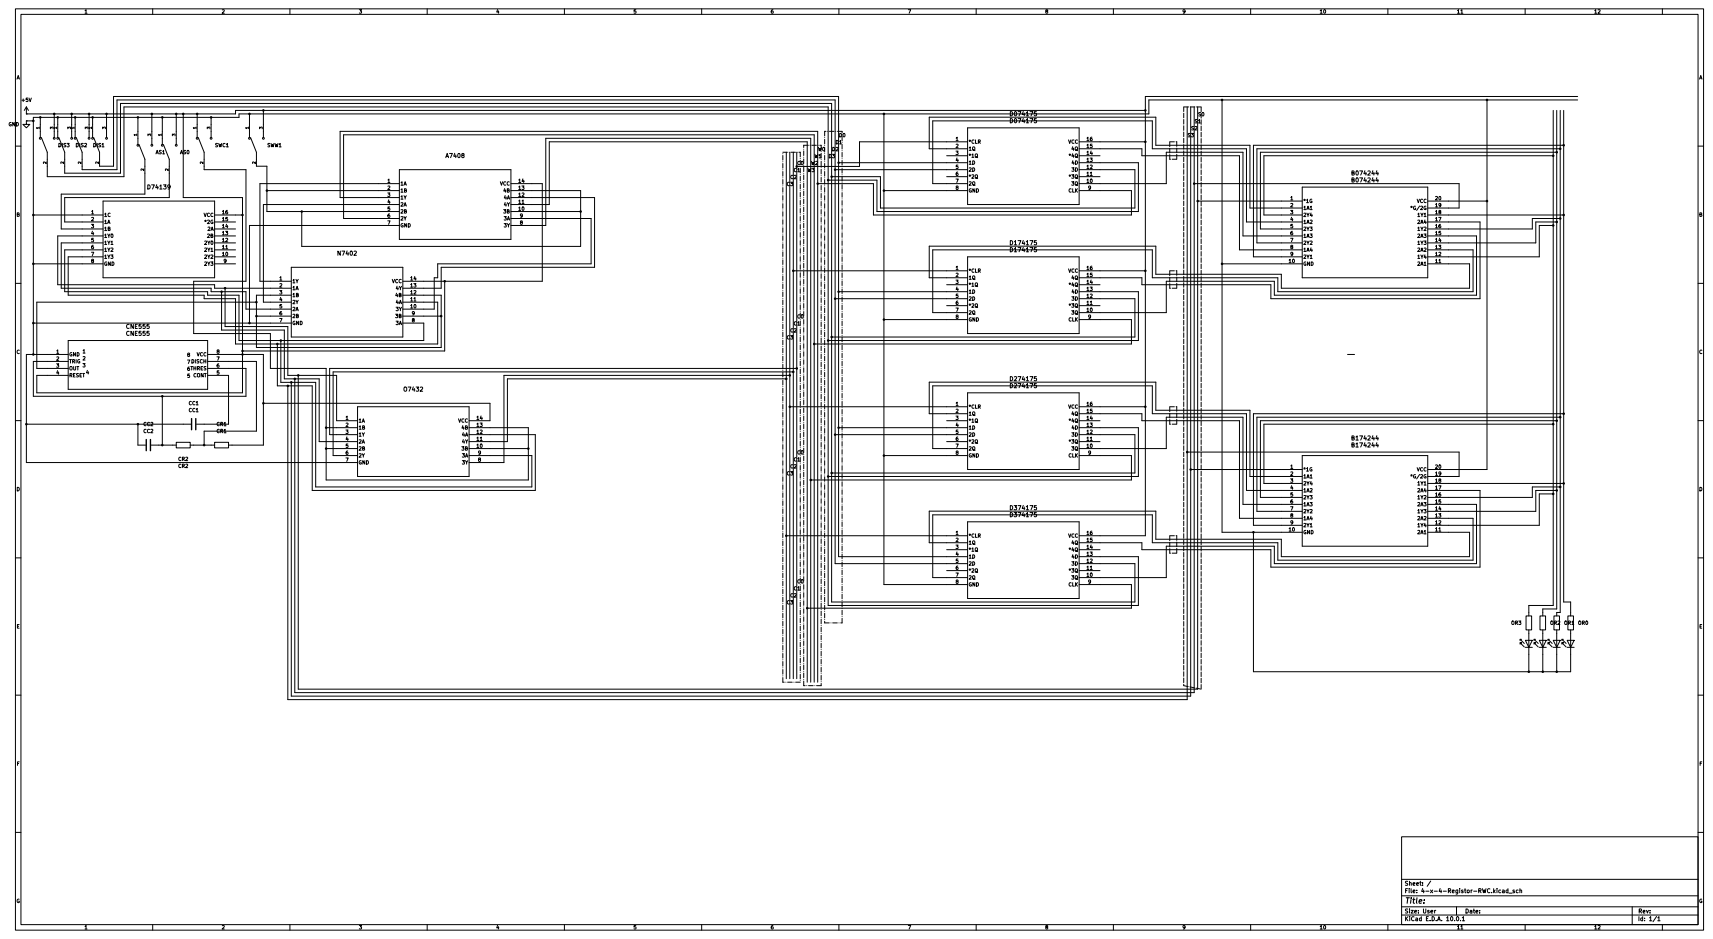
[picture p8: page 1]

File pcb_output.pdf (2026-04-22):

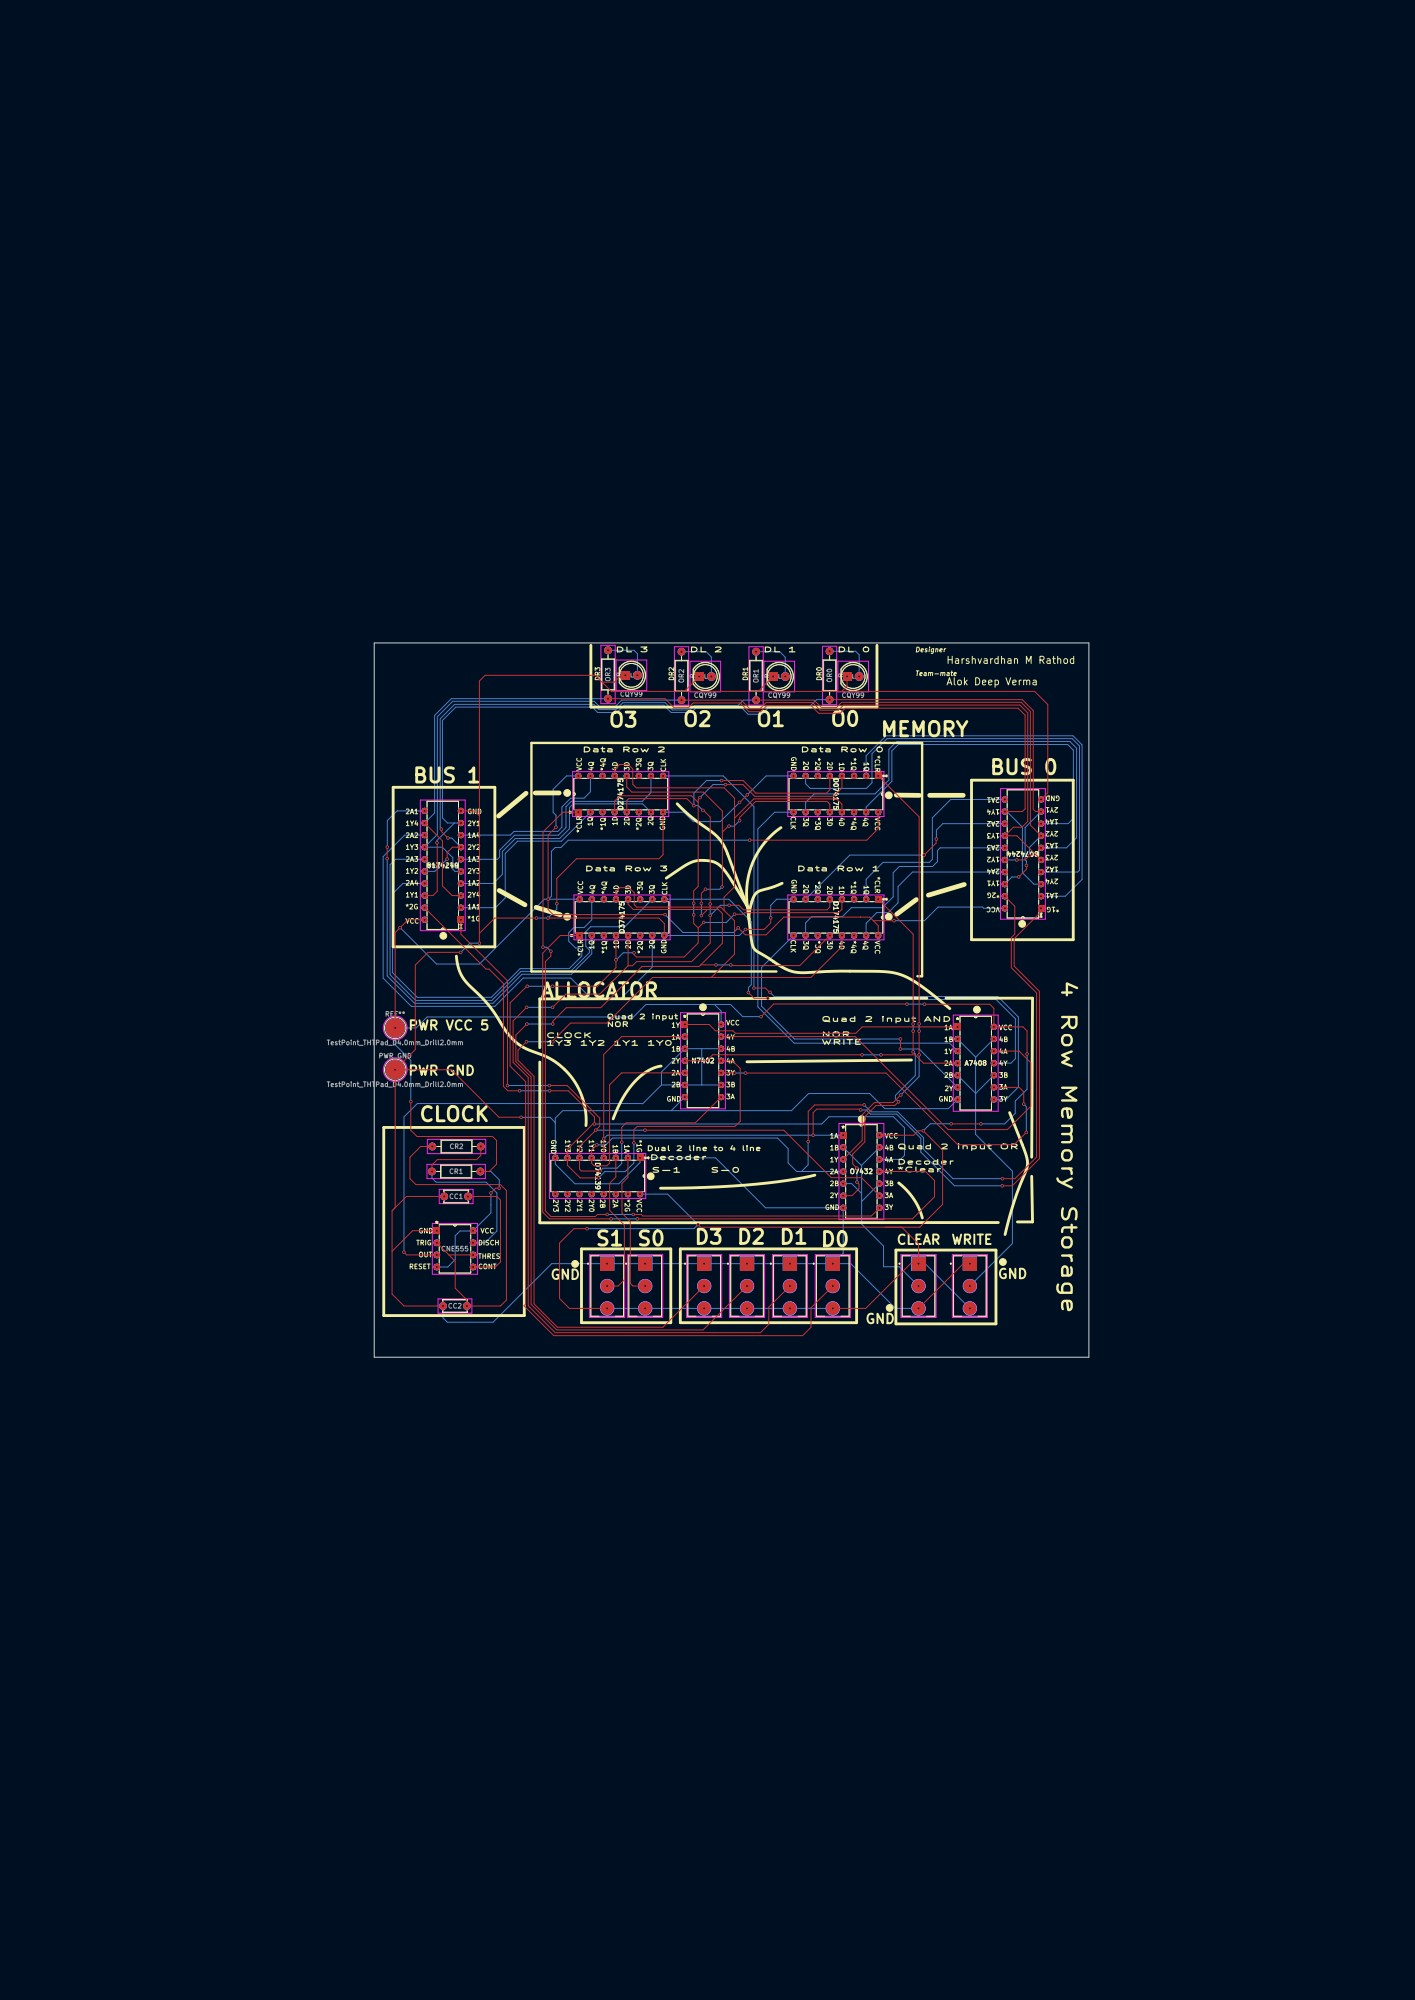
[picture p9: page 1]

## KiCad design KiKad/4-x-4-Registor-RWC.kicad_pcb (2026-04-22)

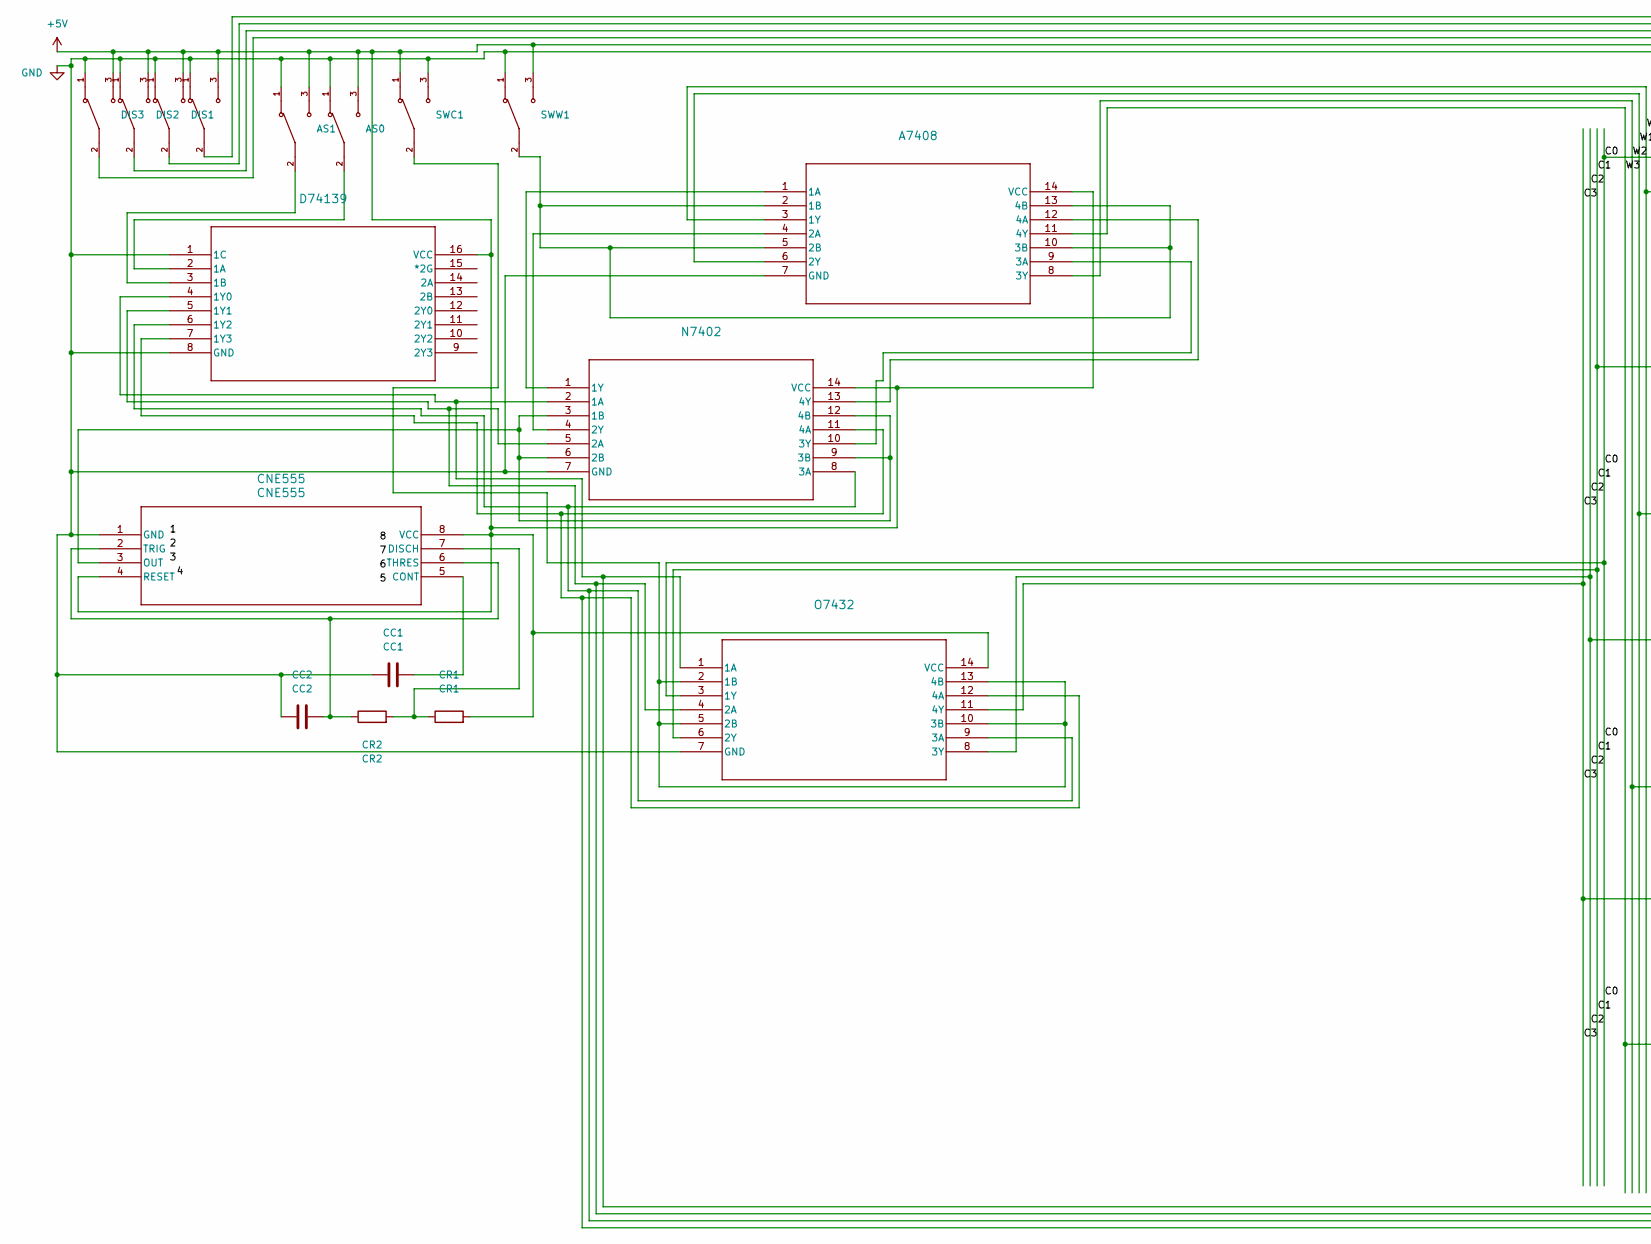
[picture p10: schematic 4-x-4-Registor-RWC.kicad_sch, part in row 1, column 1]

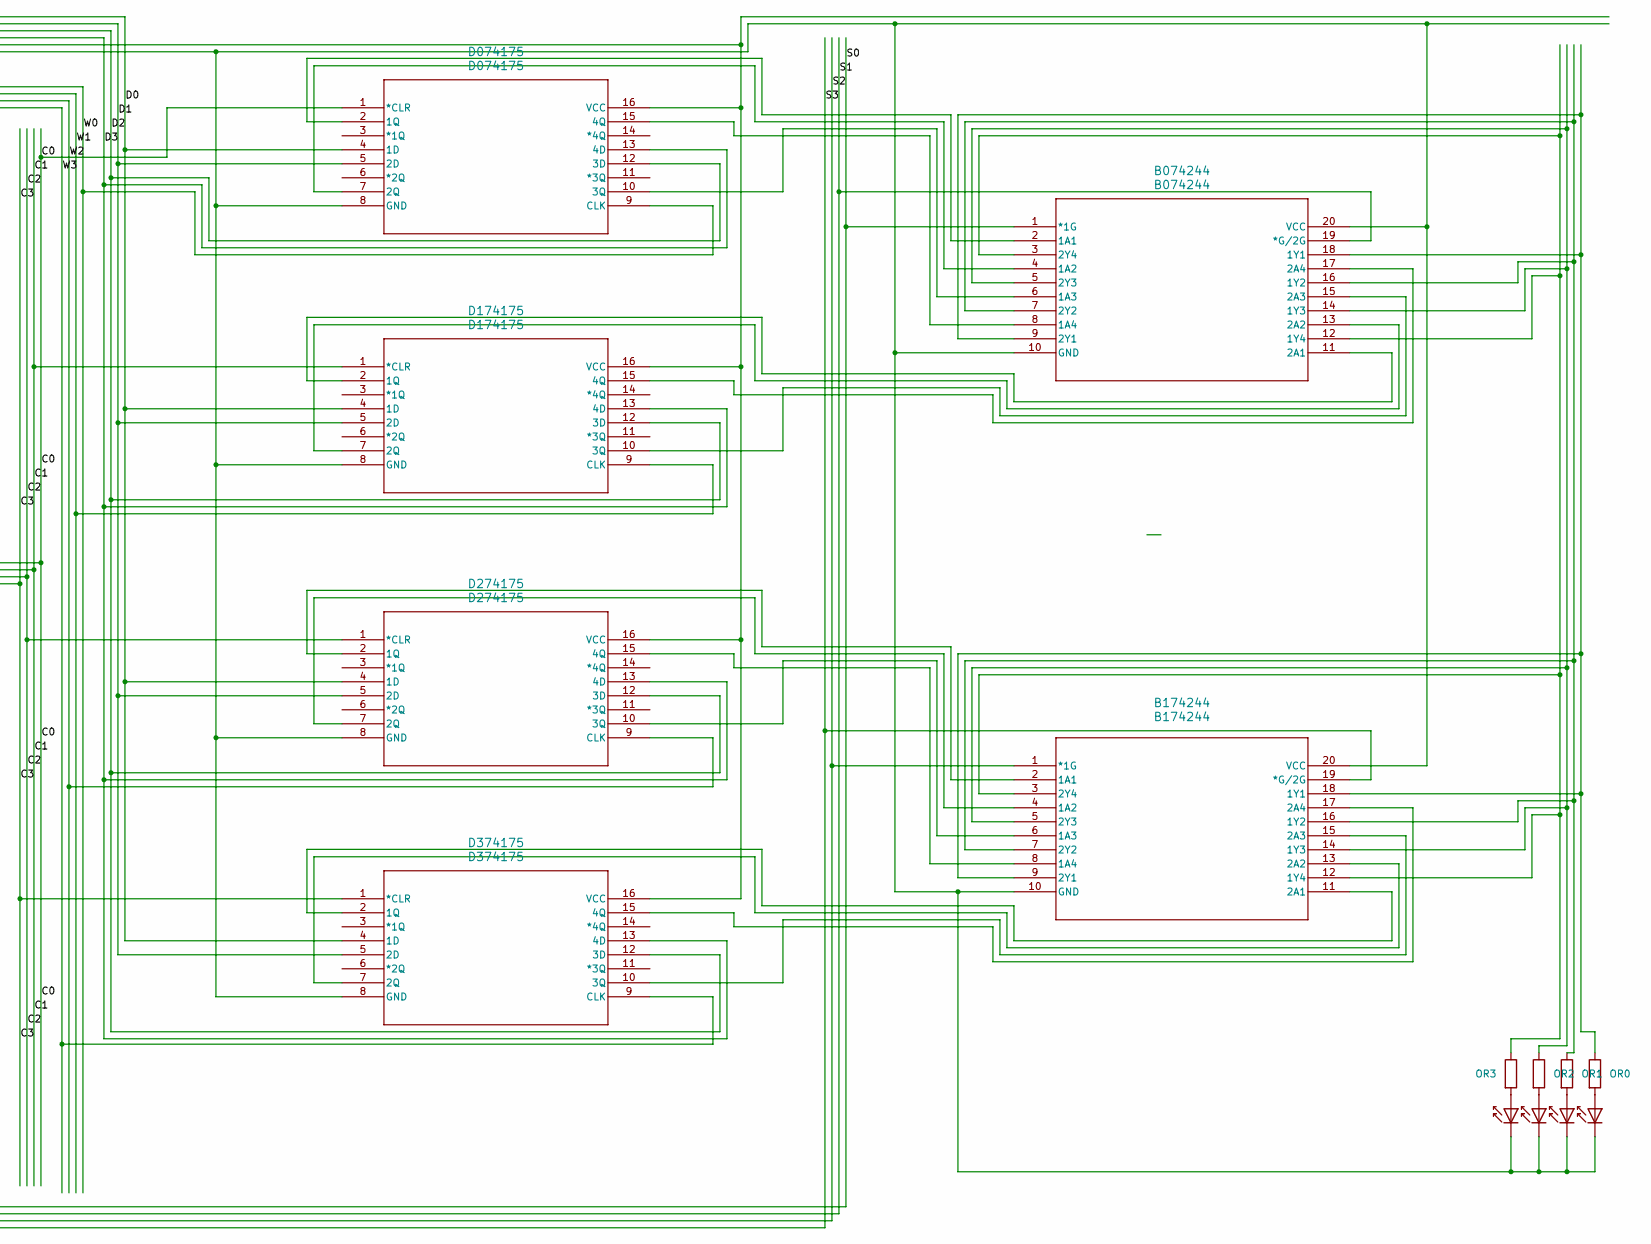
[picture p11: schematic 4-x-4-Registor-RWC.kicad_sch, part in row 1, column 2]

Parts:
A7408: A7408; SN74LS08N
AS0: AS0; SW_100SP1T1B4M2QE; PARTREV E
AS1: AS1; SW_100SP1T1B4M2QE; PARTREV E
B074244: B074244; SN74LS244N
B174244: B174244; SN74LS244N
CC1: CC1; C_Disc_D5.0mm_W2.5mm_P5.00mm
CC2: CC2; C_Disc_D5.0mm_W2.5mm_P5.00mm
CNE555: CNE555; NE555P
CR1: CR1; R_Axial_DIN0207_L6.3mm_D2.5mm_P10.16mm_Horizontal
CR2: CR2; R_Axial_DIN0207_L6.3mm_D2.5mm_P10.16mm_Horizontal
D74139: D74139; SN74LS139AN
D074175: D074175; SN74LS175N
D174175: D174175; SN74LS175N
D274175: D274175; SN74LS175N
D374175: D374175; SN74LS175N
DIS0: DIS0; SW_100SP1T1B4M2QE; PARTREV E
DIS1: DIS1; SW_100SP1T1B4M2QE; PARTREV E
DIS2: DIS2; SW_100SP1T1B4M2QE; PARTREV E
DIS3: DIS3; SW_100SP1T1B4M2QE; PARTREV E
N7402: N7402; SN7402N
O7432: O7432; SN7432N
OL0, OL1, OL2, OL3: CQY99; LED_D5.0mm
OR0, OR1, OR2, OR3: R; R_Axial_DIN0207_L6.3mm_D2.5mm_P10.16mm_Horizontal
SWC1: SWC; SW_100SP1T1B4M2QE; PARTREV E
SWW1: SWW; SW_100SP1T1B4M2QE; PARTREV E

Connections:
/C0: D074175.1 (*CLR), O7432.3 (1Y)
/C1: D174175.1 (*CLR), O7432.6 (2Y)
/C2: D274175.1 (*CLR), O7432.8 (3Y)
/C3: D374175.1 (*CLR), O7432.11 (4Y)
/D0: D074175.4 (1D), D174175.4 (1D), D274175.4 (1D), D374175.4 (1D), DIS0.2
/D1: D074175.5 (2D), D174175.5 (2D), D274175.5 (2D), D374175.5 (2D), DIS1.2
/D2: D074175.12 (3D), D174175.12 (3D), D274175.12 (3D), D374175.12 (3D), DIS2.2
/D3: D074175.13 (4D), D174175.13 (4D), D274175.13 (4D), D374175.13 (4D), DIS3.2
/S0: B074244.1 (*1G), D74139.4 (1Y0), N7402.2 (1A), O7432.1 (1A)
/S1: B074244.19 (*G/2G), D74139.5 (1Y1), N7402.5 (2A), O7432.4 (2A)
/S2: B174244.1 (*1G), D74139.6 (1Y2), N7402.8 (3A), O7432.9 (3A)
/S3: B174244.19 (*G/2G), D74139.7 (1Y3), N7402.11 (4A), O7432.12 (4A)
/W0: A7408.3 (1Y), D074175.9 (CLK)
/W1: A7408.6 (2Y), D174175.9 (CLK)
/W2: A7408.8 (3Y), D274175.9 (CLK)
/W3: A7408.11 (4Y), D374175.9 (CLK)
unnamed: A7408.1 (1A), N7402.1 (1Y)
unnamed: A7408.2 (1B), A7408.5 (2B), A7408.10 (3B), A7408.13 (4B), SWW1.2
unnamed: A7408.4 (2A), N7402.4 (2Y)
unnamed: A7408.9 (3A), N7402.10 (3Y)
unnamed: A7408.12 (4A), N7402.13 (4Y)
unnamed: B074244.2 (1A1), D074175.2 (1Q)
unnamed: B074244.4 (1A2), D074175.7 (2Q)
unnamed: B074244.6 (1A3), D074175.10 (3Q)
unnamed: B074244.8 (1A4), D074175.15 (4Q)
unnamed: B074244.9 (2Y1), B074244.18 (1Y1), B174244.9 (2Y1), B174244.18 (1Y1), OR0.1
unnamed: B074244.7 (2Y2), B074244.16 (1Y2), B174244.7 (2Y2), B174244.16 (1Y2), OR1.1
unnamed: B074244.5 (2Y3), B074244.14 (1Y3), B174244.5 (2Y3), B174244.14 (1Y3), OR2.1
unnamed: B074244.3 (2Y4), B074244.12 (1Y4), B174244.3 (2Y4), B174244.12 (1Y4), OR3.1
unnamed: B074244.11 (2A1), D174175.2 (1Q)
unnamed: B074244.13 (2A2), D174175.7 (2Q)
unnamed: B074244.15 (2A3), D174175.10 (3Q)
unnamed: B074244.17 (2A4), D174175.15 (4Q)
unnamed: B174244.2 (1A1), D274175.2 (1Q)
unnamed: B174244.4 (1A2), D274175.7 (2Q)
unnamed: B174244.6 (1A3), D274175.10 (3Q)
unnamed: B174244.8 (1A4), D274175.15 (4Q)
unnamed: B174244.11 (2A1), D374175.2 (1Q)
unnamed: B174244.13 (2A2), D374175.7 (2Q)
unnamed: B174244.15 (2A3), D374175.10 (3Q)
unnamed: B174244.17 (2A4), D374175.15 (4Q)
unnamed: CC1.2, CNE555.5 (CONT)
unnamed: CNE555.7 (DISCH), CR1.1, CR2.2
unnamed: CNE555.3 (OUT), N7402.3 (1B), N7402.6 (2B), N7402.9 (3B), N7402.12 (4B)
unnamed: CC2.2, CNE555.2 (TRIG), CNE555.6 (THRES), CR2.1
unnamed: AS0.2, D74139.2 (1A)
unnamed: AS1.2, D74139.3 (1B)
unnamed: O7432.2 (1B), O7432.5 (2B), O7432.10 (3B), O7432.13 (4B), SWC1.2
unnamed: OL0.2 (A), OR0.2
unnamed: OL1.2 (A), OR1.2
unnamed: OL2.2 (A), OR2.2
unnamed: OL3.2 (A), OR3.2

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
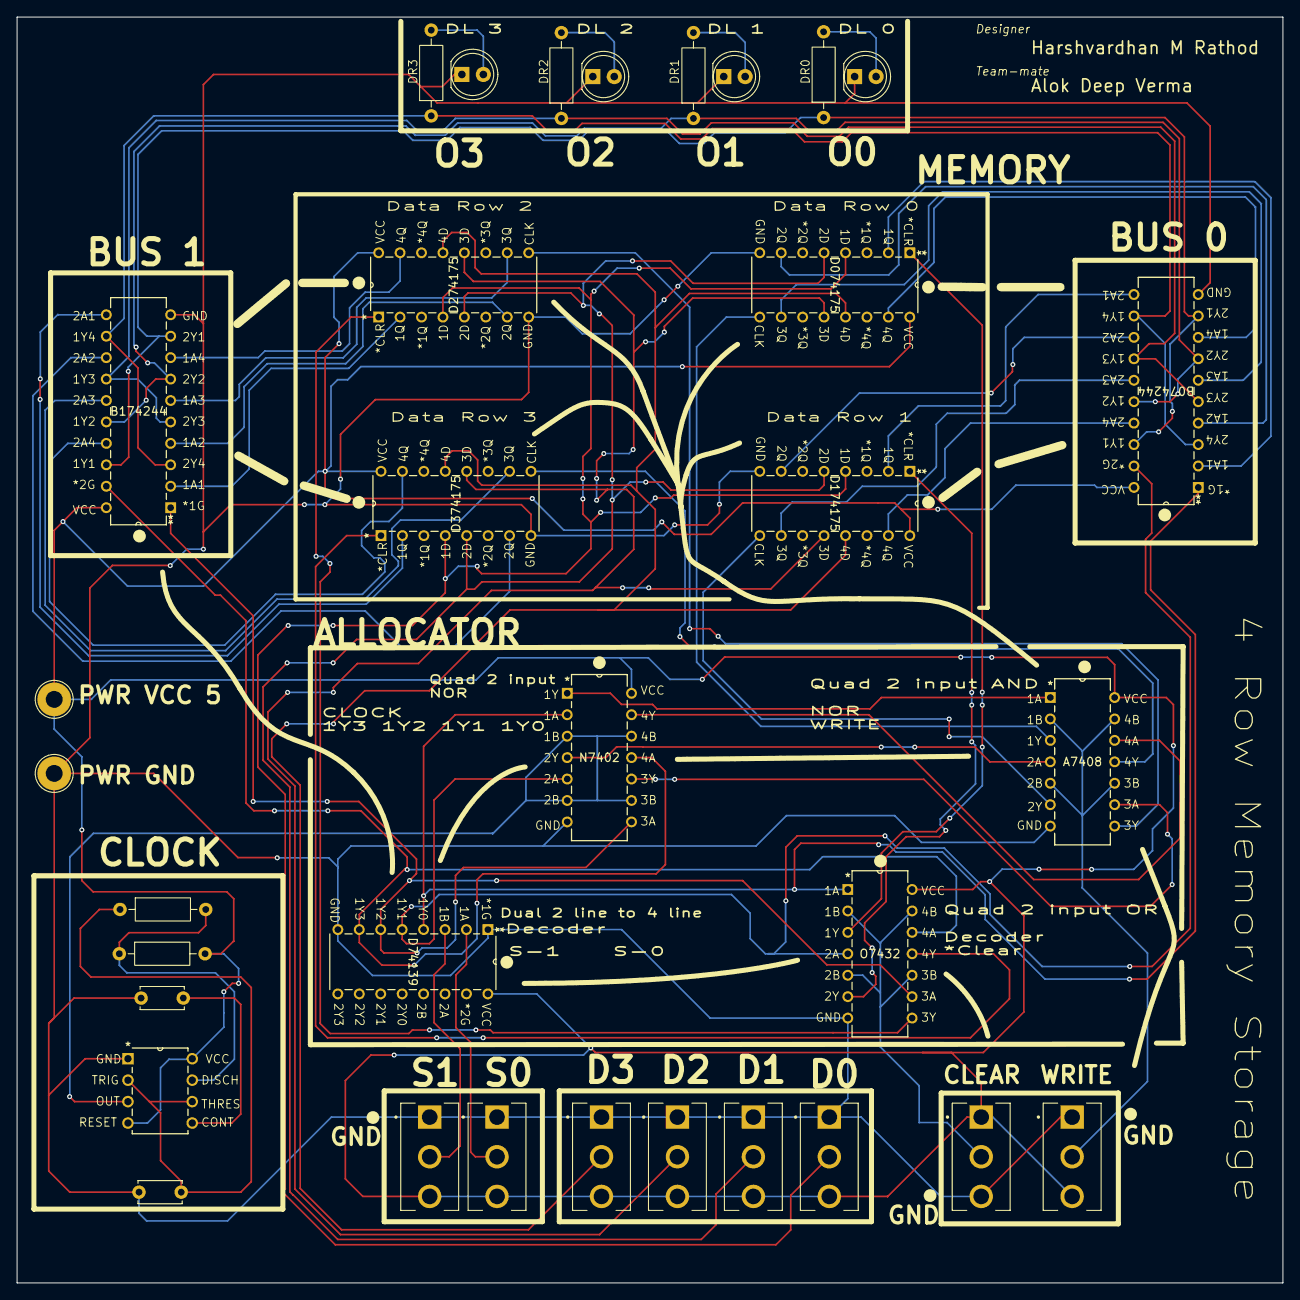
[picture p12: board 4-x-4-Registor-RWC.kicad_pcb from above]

Board: 2 copper layers, 150.0 x 150.0 mm, 32 parts (0 on the bottom side), 54 nets.

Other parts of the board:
PWR GND: TestPoint_THTPad_D4.0mm_Drill2.0mm

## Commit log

2026-04-01 updated files
    [100SP1T1B4M2QE.STEP, 100SP1T1B4M2QE.step, 4-x-4-Registor-RWC.kicad_pcb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]
2026-04-22 files updated Finalised
    [4-x-4-Registor-RWC.kicad_pcb]
